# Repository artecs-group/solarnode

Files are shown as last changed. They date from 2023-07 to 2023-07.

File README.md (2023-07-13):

# Solar Node

This is a kikad project for a pcb of a IoT node that can meassure Solar Irradiation
and send it truogh a wifi conection to a cloud service.

The node ins based on an ESP32, which provides the microcontroller and the wifi
radio. The pcb adds a power supply system and a solar irradiance meassurement
circuit.

The power supply system is composed of a Lipo battery, a battery charger, a 6W
solar pannel and a set of regulators: one for the esp, and two for external
devices that can be swithced on or off from the ESP firmware.

The solar irradiance meassurement circuit is composed of a transimpedance
amplifier and a small mono-chrystalline fotovoltaic cell, that is kept in short
circuit by the transimpedance amplifier, which transforms the current generated
by the cell into a voltage that can be read using one of the ADC channels of the
ESP32. Bellow you can see an image of a complete node build from this pcb. 

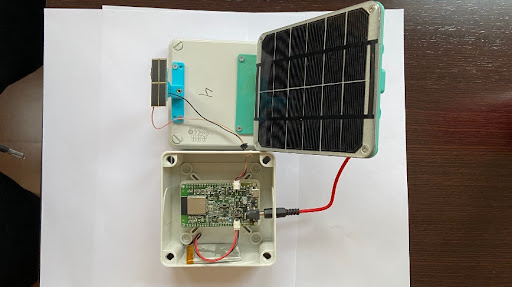
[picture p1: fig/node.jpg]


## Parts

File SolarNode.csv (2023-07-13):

Id | Designator | Package | Quantity | Designation | Supplier and ref
1 | SW5 | SW_SPST_B3U-1000P | 1 | IO0
2 | D9,D15,D4,D16 | D_SOD-323 | 4 | BAT48JFILM
3 | SW4 | SW_SPST_B3U-1000P | 1 | EN
4 | D3,D1 | D_SMA | 2 | MBRA340
5 | R20 | R_0603_1608Metric_0.65 | 1 | 453K
6 | H1,H3,H4,H2 | MountingHole_2.2mm_M2 | 4 | MountingHole
7 | R31,R30,R29 | R_0603_1608Metric_0.65 | 3 | 1M
8 | R8,R15,R28,R32,R7,R40,R25,R42,R33,R27,R9,R4,R6 | R_0603_1608Metric_0.65 | 13 | 10K
9 | U8 | MSOP-8_3x3mm_P0.65mm | 1 | OPA2356xxD
10 | C33,C45,C44,C32,C34,C23,C24,C19,C42,C30 | C_0603_1608Metric | 10 | 0.1u
11 | R12 | R_0603_1608Metric_0.65 | 1 | 5.90K
12 | R18 | R_0603_1608Metric_0.65 | 1 | 422K
13 | C1 | CP_Radial_D6.3mm_P2.50mm | 1 | 100u
14 | C3,C9,C20,C16,C27,C6,C5,C4,C22,C10,C36,C12,C8,C26,C2,C18,C11 | C_0603_1608Metric | 17 | 10u
15 | R5,R24,R11,R23,R22,R37 | R_0603_1608Metric_0.65 | 6 | 1K
16 | U3,U4 | SOT-23-5 | 2 | RT9080-33GJ5
17 | R10,R46,R45 | R_0603_1608Metric_0.65 | 3 | 0R
18 | R17 | R_0603_1608Metric_0.65 | 1 | 10M
19 | D7 | LED_0603_1608Metric | 1 | CHG
20 | Y1 | Crystal_SMD_3215-2Pin_3.2x1.5mm | 1 | 32.768KHz
21 | C40,C41 | C_0603_1608Metric | 2 | 12p
22 | FID3,FID1,FID4,FID2 | Fiducial_1mm_Mask3mm | 4 | Fiducial
23 | J2 | JST_PH_S2B-PH-SM4-TB_1x02-1MP_P2.00mm_Horizontal | 1 | TIA
24 | D11 | LED_0603_1608Metric | 1 | 3VA
25 | C14,C15 | C_0603_1608Metric | 2 | 1n
26 | R2,R3 | R_0603_1608Metric_0.65 | 2 | 5.1K
27 | U6 | QFN-24-1EP_4x4mm_P0.5mm_EP2.6x2.6mm | 1 | CP2104
28 | D6 | LED_0603_1608Metric | 1 | BATT!
29 | R26 | R_0603_1608Metric_0.65 | 1 | 30K
30 | U1 | VQFN-16-1EP_3x3mm_P0.5mm_EP1.6x1.6mm_ThermalVias | 1 | BQ24074RGT
31 | SW1 | SW_DPDT_CK_JS202011JCQN | 1 | BATT_SW
32 | R43 | R_0603_1608Metric_0.65 | 1 | 16.5R
33 | D14 | LED_0603_1608Metric | 1 | IO2
34 | C25 | C_0603_1608Metric | 1 | 1.8n
35 | R14 | R_0603_1608Metric_0.65 | 1 | 887R
36 | D8 | LED_0603_1608Metric | 1 | PG
37 | U7 | ESP32-WROOM-32 | 1 | ESP32-WROOM-32E
38 | J3 | GCT_USB4110-GF-A_REVB | 1 | USB_C_Receptacle_USB2.0
39 | L1 | L_Vishay_IFSC-1515AH_4x4x1.8mm | 1 | 8.2u
40 | SW3 | SW_SPST_B3U-1000P | 1 | LED
41 | U2 | SOT-23-6 | 1 | TPS3780A
42 | Q2 | SOT-363_SC-70-6 | 1 | MUN5214DW1
43 | J1 | BarrelJack_CLIFF_FC681465S_SMT_Horizontal | 1 | 10V_MAX
44 | R34,R35 | R_0603_1608Metric_0.65 | 2 | 2.2K
45 | R13 | R_0603_1608Metric_0.65 | 1 | 1.78K
46 | C38,C31 | C_0603_1608Metric | 2 | 1u
47 | U10 | SOT-363_SC-70-6 | 1 | NUP2202
48 | U9 | SOT-23-6 | 1 | MCP1501-10xCH
49 | D2 | LED_0603_1608Metric | 1 | DC!
50 | R16 | R_0603_1608Metric_0.65 | 1 | 750K
51 | J6 | JST_PH_S2B-PH-SM4-TB_1x02-1MP_P2.00mm_Horizontal | 1 | Li_3.7V
52 | R44 | R_0603_1608Metric_0.65 | 1 | 2R
53 | Q1 | SOT-23 | 1 | AO3400A
54 | R19 | R_0603_1608Metric_0.65 | 1 | 698K
55 | R41 | R_0603_1608Metric_0.65 | 1 | 7.5M
56 | SW2 | SW_DPDT_CK_JS202011JCQN | 1 | SYS_SW
57 | D13 | D_SOD-123F | 1 | MBR1020VL
58 | TH1 | C_Disc_D5.0mm_W2.5mm_P2.50mm | 1 | 103AT (NC)
59 | D10 | LED_0603_1608Metric | 1 | 3V
60 | U5 | SOT-23-5 | 1 | LM2735XMF
61 | R1 | R_0603_1608Metric_0.65 | 1 | 1K
62 | D12 | LED_0603_1608Metric | 1 | 5V
63 | R21 | R_0603_1608Metric_0.65 | 1 | 200K
64 | JP8 | SolderJumper-2_P1.3mm_Open_RoundedPad1.0x1.5mm | 1 | BOOST
65 | J5,J4 | PinHeader_1x18_P2.54mm_Vertical | 2 | Conn_01x18
66 | JP5 | SolderJumper-2_P1.3mm_Open_RoundedPad1.0x1.5mm | 1 | 0.50A
67 | JP7 | SolderJumper-2_P1.3mm_Open_RoundedPad1.0x1.5mm | 1 | SUP
68 | JP6 | SolderJumper-2_P1.3mm_Open_RoundedPad1.0x1.5mm | 1 | 1.00A
69 | JP3 | SolderJumper-2_P1.3mm_Open_RoundedPad1.0x1.5mm | 1 | TS
70 | JP4 | SolderJumper-2_P1.3mm_Open_RoundedPad1.0x1.5mm | 1 | 0.15A

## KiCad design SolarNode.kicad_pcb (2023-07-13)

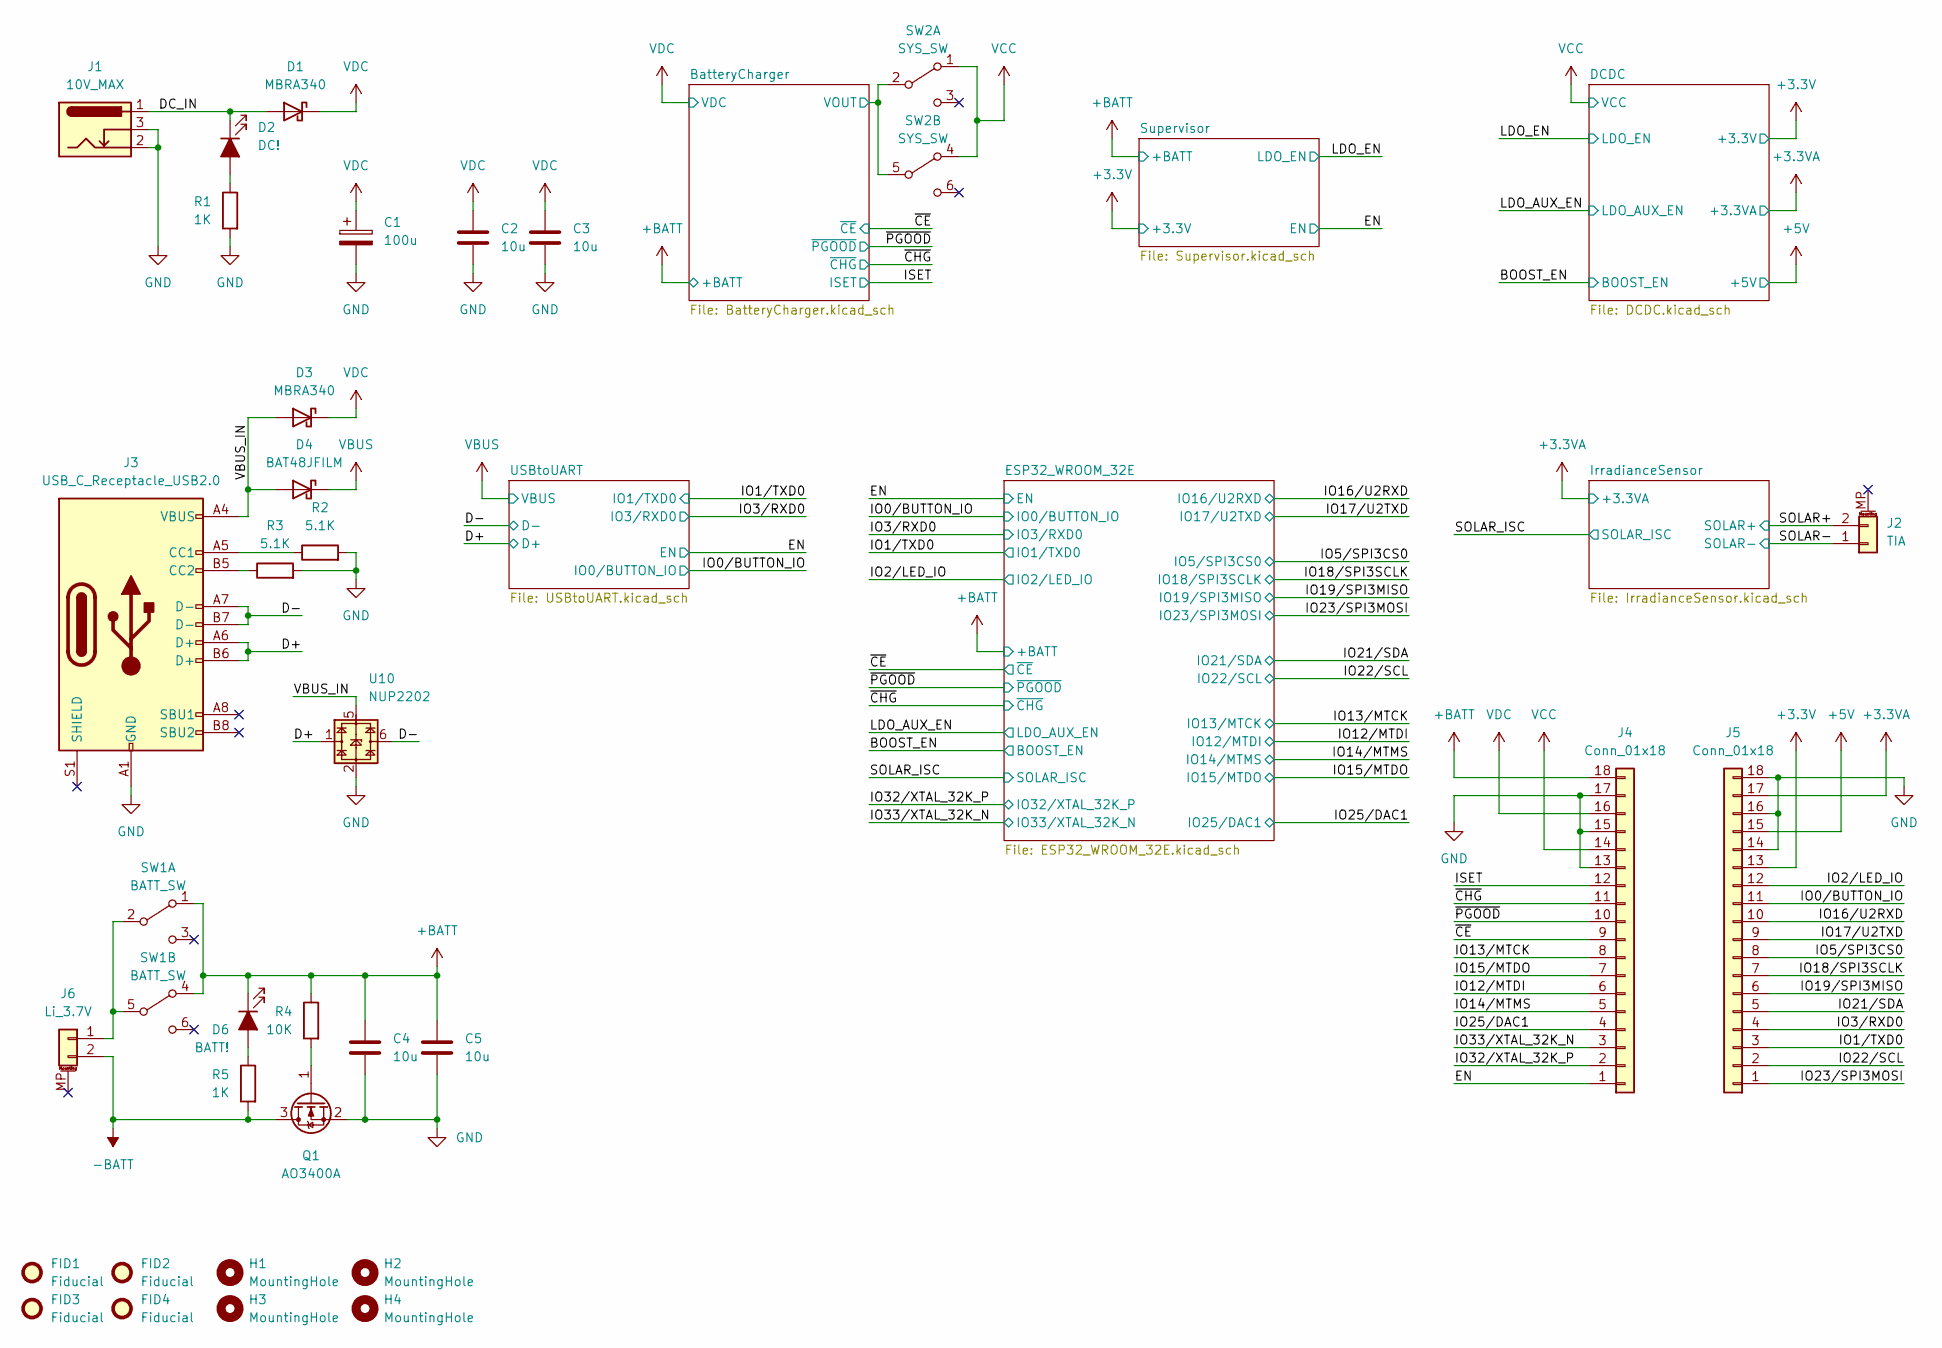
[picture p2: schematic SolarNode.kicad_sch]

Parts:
C1: 100u; CP_Radial_D6.3mm_P2.50mm; MPN 16YXF100MEFCT16.3X11
C2, C3, C4, C5: 10u; C_0603_1608Metric; MPN CC0603MRX5R7BB106
D1, D3: MBRA340; D_SMA; MPN MBRA340
D2: DC!; LED_0603_1608Metric; MPN 150060SS75000
D4: BAT48JFILM; D_SOD-323; MPN BAT48JFILM
D6: BATT!; LED_0603_1608Metric; MPN 150060SS75000
FID1, FID2, FID3, FID4: Fiducial; Fiducial_1mm_Mask3mm
H1, H2, H3, H4: MountingHole; MountingHole_2.2mm_M2
J1: 10V_MAX; BarrelJack_CLIFF_FC681465S_SMT_Horizontal; MPN FC681465S
J2: TIA; JST_PH_S2B-PH-SM4-TB_1x02-1MP_P2.00mm_Horizontal; MPN S2B-PH-SM4-TB(LF)(SN)
J3: USB_C_Receptacle_USB2.0; GCT_USB4110-GF-A_REVB; MPN USB4110-GF-A
J4, J5: Conn_01x18; PinHeader_1x18_P2.54mm_Vertical; MPN PH1-18-UA
J6: Li_3.7V; JST_PH_S2B-PH-SM4-TB_1x02-1MP_P2.00mm_Horizontal; MPN S2B-PH-SM4-TB(LF)(SN)
Q1: AO3400A; SOT-23; MPN AO3400A
R1, R5: 1K; R_0603_1608Metric_0.65; MPN RC0603FR-071KL
R2, R3: 5.1K; R_0603_1608Metric_0.65; MPN RC0603FR-075K1L
R4: 10K; R_0603_1608Metric_0.65; MPN RC0603FR-0710KL
SW1: BATT_SW; SW_DPDT_CK_JS202011JCQN; MPN JS202011JCQN
SW2: SYS_SW; SW_DPDT_CK_JS202011JCQN; MPN JS202011JCQN
U10: NUP2202; SOT-363_SC-70-6; MPN NUP2202W1T2G

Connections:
+3.3VA: J5.17; also elsewhere on the board
+3V3: J5.13; also elsewhere on the board
+5V: J5.15; also elsewhere on the board
+BATT: C4.1, C5.1, D6.1 (K), J4.18, R4.1, SW1.1 (A), SW1.4 (A); also elsewhere on the board
-BATT: J6.2, Q1.3 (D), R5.2
/BatteryCharger/VOUT: SW2.2 (B), SW2.5 (B); also elsewhere on the board
/D+: J3.A6 (D+), J3.B6 (D+), U10.1; also elsewhere on the board
/D-: J3.A7 (D-), J3.B7 (D-), U10.6; also elsewhere on the board
/DC_IN: D1.2 (A), D2.1 (K), J1.1
/EN: J4.1; also elsewhere on the board
/IO0/BUTTON_IO: J5.11; also elsewhere on the board
/IO1/TXD0: J5.3; also elsewhere on the board
/IO2/LED_IO: J5.12; also elsewhere on the board
/IO3/RXD0: J5.4; also elsewhere on the board
/IO5/SPI3CS0: J5.8; also elsewhere on the board
/IO12/MTDI: J4.6; also elsewhere on the board
/IO13/MTCK: J4.8; also elsewhere on the board
/IO14/MTMS: J4.5; also elsewhere on the board
/IO15/MTDO: J4.7; also elsewhere on the board
/IO16/U2RXD: J5.10; also elsewhere on the board
/IO17/U2TXD: J5.9; also elsewhere on the board
/IO18/SPI3SCLK: J5.7; also elsewhere on the board
/IO19/SPI3MISO: J5.6; also elsewhere on the board
/IO21/SDA: J5.5; also elsewhere on the board
/IO22/SCL: J5.2; also elsewhere on the board
/IO23/SPI3MOSI: J5.1; also elsewhere on the board
/IO25/DAC1: J4.4; also elsewhere on the board
/IO32/XTAL_32K_P: J4.2; also elsewhere on the board
/IO33/XTAL_32K_N: J4.3; also elsewhere on the board
/ISET: J4.12; also elsewhere on the board
/SOLAR+: J2.2; also elsewhere on the board
/SOLAR-: J2.1; also elsewhere on the board
/VBUS_IN: D3.2 (A), D4.2 (A), J3.A4 (VBUS), J3.A9 (VBUS), J3.B4 (VBUS), J3.B9 (VBUS), U10.5
/~CE: J4.9; also elsewhere on the board
/~CHG: J4.11; also elsewhere on the board
/~PGOOD: J4.10; also elsewhere on the board
GND: C1.2, C2.2, C3.2, C4.2, C5.2, J1.2, J1.3, J3.A1 (GND), J3.A12 (GND), J3.B1 (GND), J3.B12 (GND), J4.13, J4.15, J4.17, J5.14, J5.16, J5.18, Q1.2 (S), R1.2, R2.2, R3.2, U10.2; also elsewhere on the board
unnamed: D2.2 (A), R1.1
unnamed: D6.2 (A), R5.1
unnamed: J3.A5 (CC1), R2.1
unnamed: J3.B5 (CC2), R3.1
unnamed: J6.1, SW1.2 (B), SW1.5 (B)
unnamed: Q1.1 (G), R4.2
VBUS: D4.1 (K); also elsewhere on the board
VCC: J4.14, SW2.1 (A), SW2.4 (A); also elsewhere on the board
VDC: C1.1, C2.1, C3.1, D1.1 (K), D3.1 (K), J4.16; also elsewhere on the board

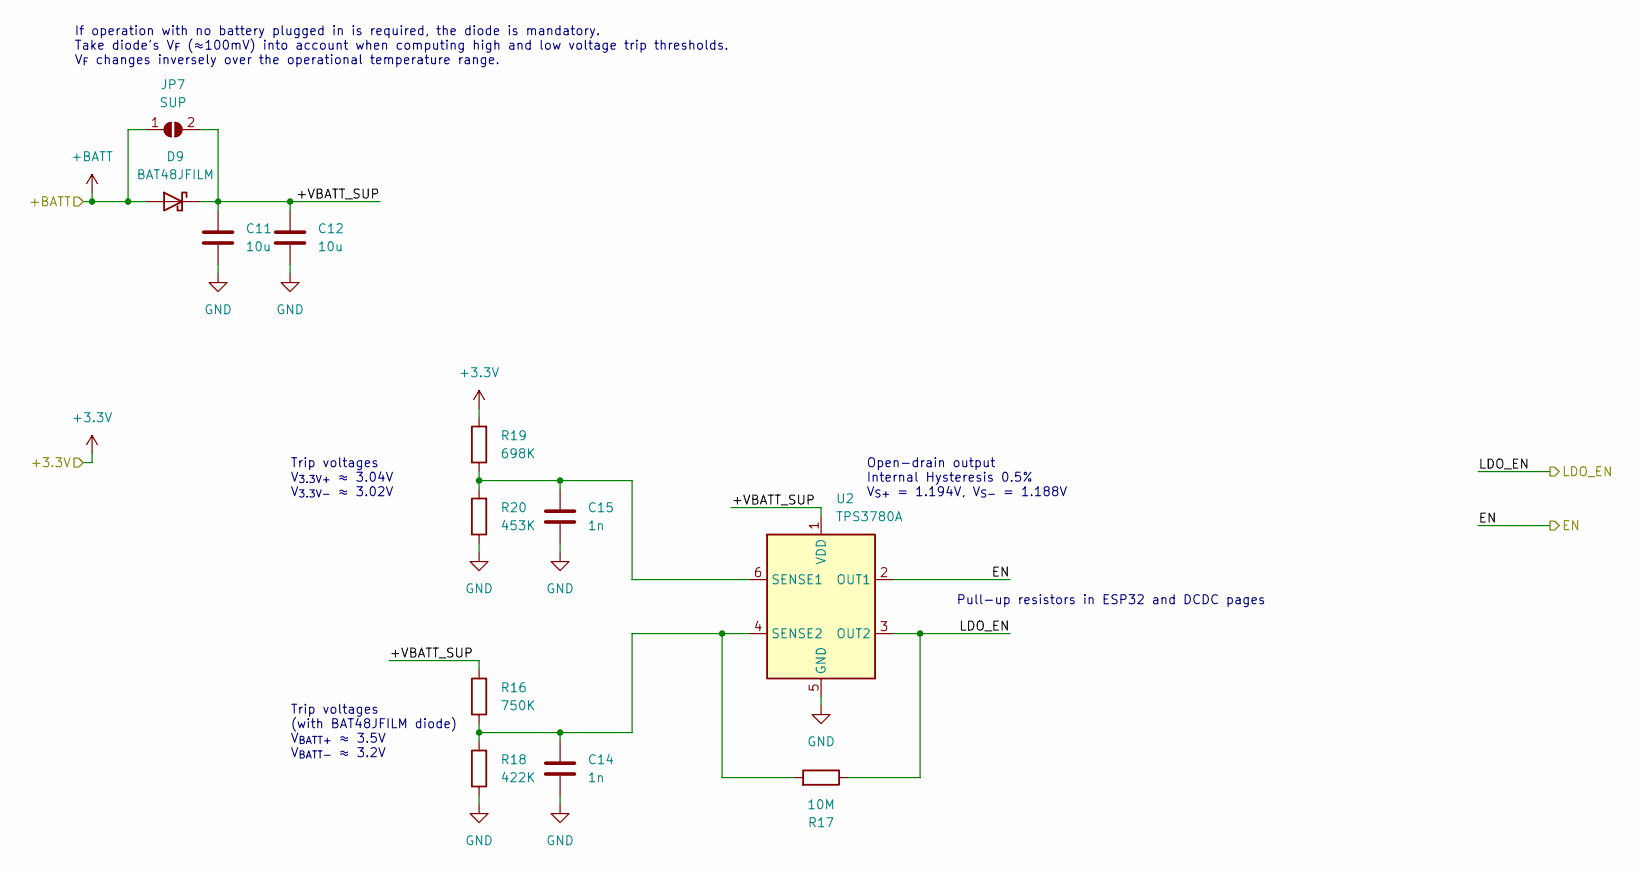
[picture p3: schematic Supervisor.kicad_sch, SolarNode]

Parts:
C11, C12: 10u; C_0603_1608Metric; MPN CC0603MRX5R7BB106
C14, C15: 1n; C_0603_1608Metric; MPN CC0603KRX7R9BB102
D9: BAT48JFILM; D_SOD-323; MPN BAT48JFILM
JP7: SUP; SolderJumper-2_P1.3mm_Open_RoundedPad1.0x1.5mm
R16: 750K; R_0603_1608Metric_0.65; MPN RC0603FR-07750KL
R17: 10M; R_0603_1608Metric_0.65; MPN RC0603FR-0710ML
R18: 422K; R_0603_1608Metric_0.65; MPN RC0603FR-07422KL
R19: 698K; R_0603_1608Metric_0.65; MPN RC0603FR-07698KL
R20: 453K; R_0603_1608Metric_0.65; MPN RC0603FR-07453KL
U2: TPS3780A; SOT-23-6; MPN TPS3780ADBVT

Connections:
+3V3: R19.2; also elsewhere on the board
+BATT: D9.2 (A), JP7.1 (A); also elsewhere on the board
/EN: U2.2 (OUT1); also elsewhere on the board
/LDO_EN: R17.1, U2.3 (OUT2); also elsewhere on the board
/Supervisor/+VBATT_SUP: C11.1, C12.1, D9.1 (K), JP7.2 (B), R16.2, U2.1 (VDD)
GND: C11.2, C12.2, C14.2, C15.2, R18.1, R20.1, U2.5 (GND); also elsewhere on the board
unnamed: C14.1, R16.1, R17.2, R18.2, U2.4 (SENSE2)
unnamed: C15.1, R19.1, R20.2, U2.6 (SENSE1)

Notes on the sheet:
Trip voltages V_{3.3V+} ≈ 3.04V V_{3.3V-} ≈ 3.02V
Pull-up resistors in ESP32 and DCDC pages
Trip voltages (with BAT48JFILM diode) V_{BATT+} ≈ 3.5V V_{BATT-} ≈ 3.2V
If operation with no battery plugged in is required, the diode is mandatory. Take diode's V_{F} (≈100mV) into account when computing high and low voltage trip thresholds. V_{F} changes inversely over the operational temperature range.
Open-drain output Internal Hysteresis 0.5% V_{S+} = 1.194V, V_{S-} = 1.188V

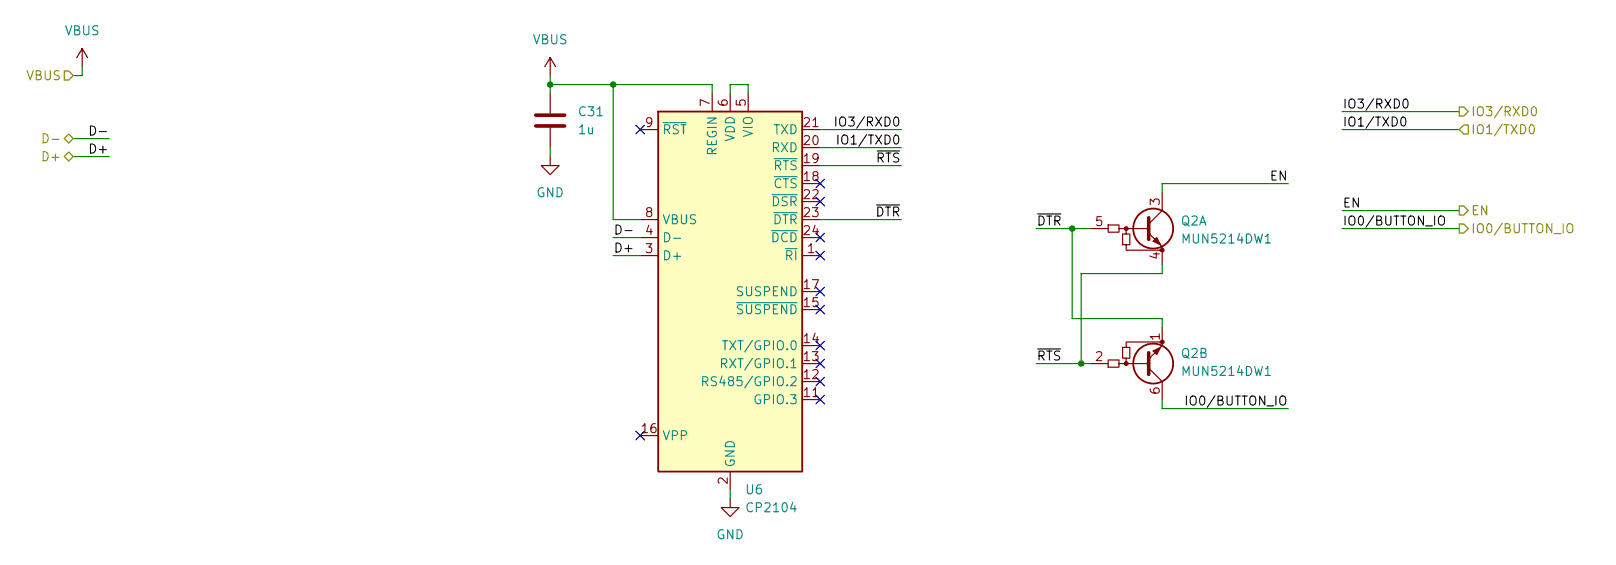
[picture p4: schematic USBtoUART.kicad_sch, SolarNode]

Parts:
C31: 1u; C_0603_1608Metric; MPN CC0603KRX7R8BB105
Q2: MUN5214DW1; SOT-363_SC-70-6; MPN MUN5214DW1T1G
U6: CP2104; QFN-24-1EP_4x4mm_P0.5mm_EP2.6x2.6mm; MPN CP2104-F03-GM

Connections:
/D+: U6.3 (D+); also elsewhere on the board
/D-: U6.4 (D-); also elsewhere on the board
/EN: Q2.3 (C1); also elsewhere on the board
/IO0/BUTTON_IO: Q2.6 (C2); also elsewhere on the board
/IO1/TXD0: U6.20 (RXD); also elsewhere on the board
/IO3/RXD0: U6.21 (TXD); also elsewhere on the board
/USBtoUART/~DTR: Q2.1 (E2), Q2.5 (B1), U6.23 (~DTR)
/USBtoUART/~RTS: Q2.2 (B2), Q2.4 (E1), U6.19 (~RTS)
GND: C31.2, U6.2 (GND), U6.25 (GND); also elsewhere on the board
unnamed: U6.5 (VIO), U6.6 (VDD)
VBUS: C31.1, U6.7 (REGIN), U6.8 (VBUS); also elsewhere on the board

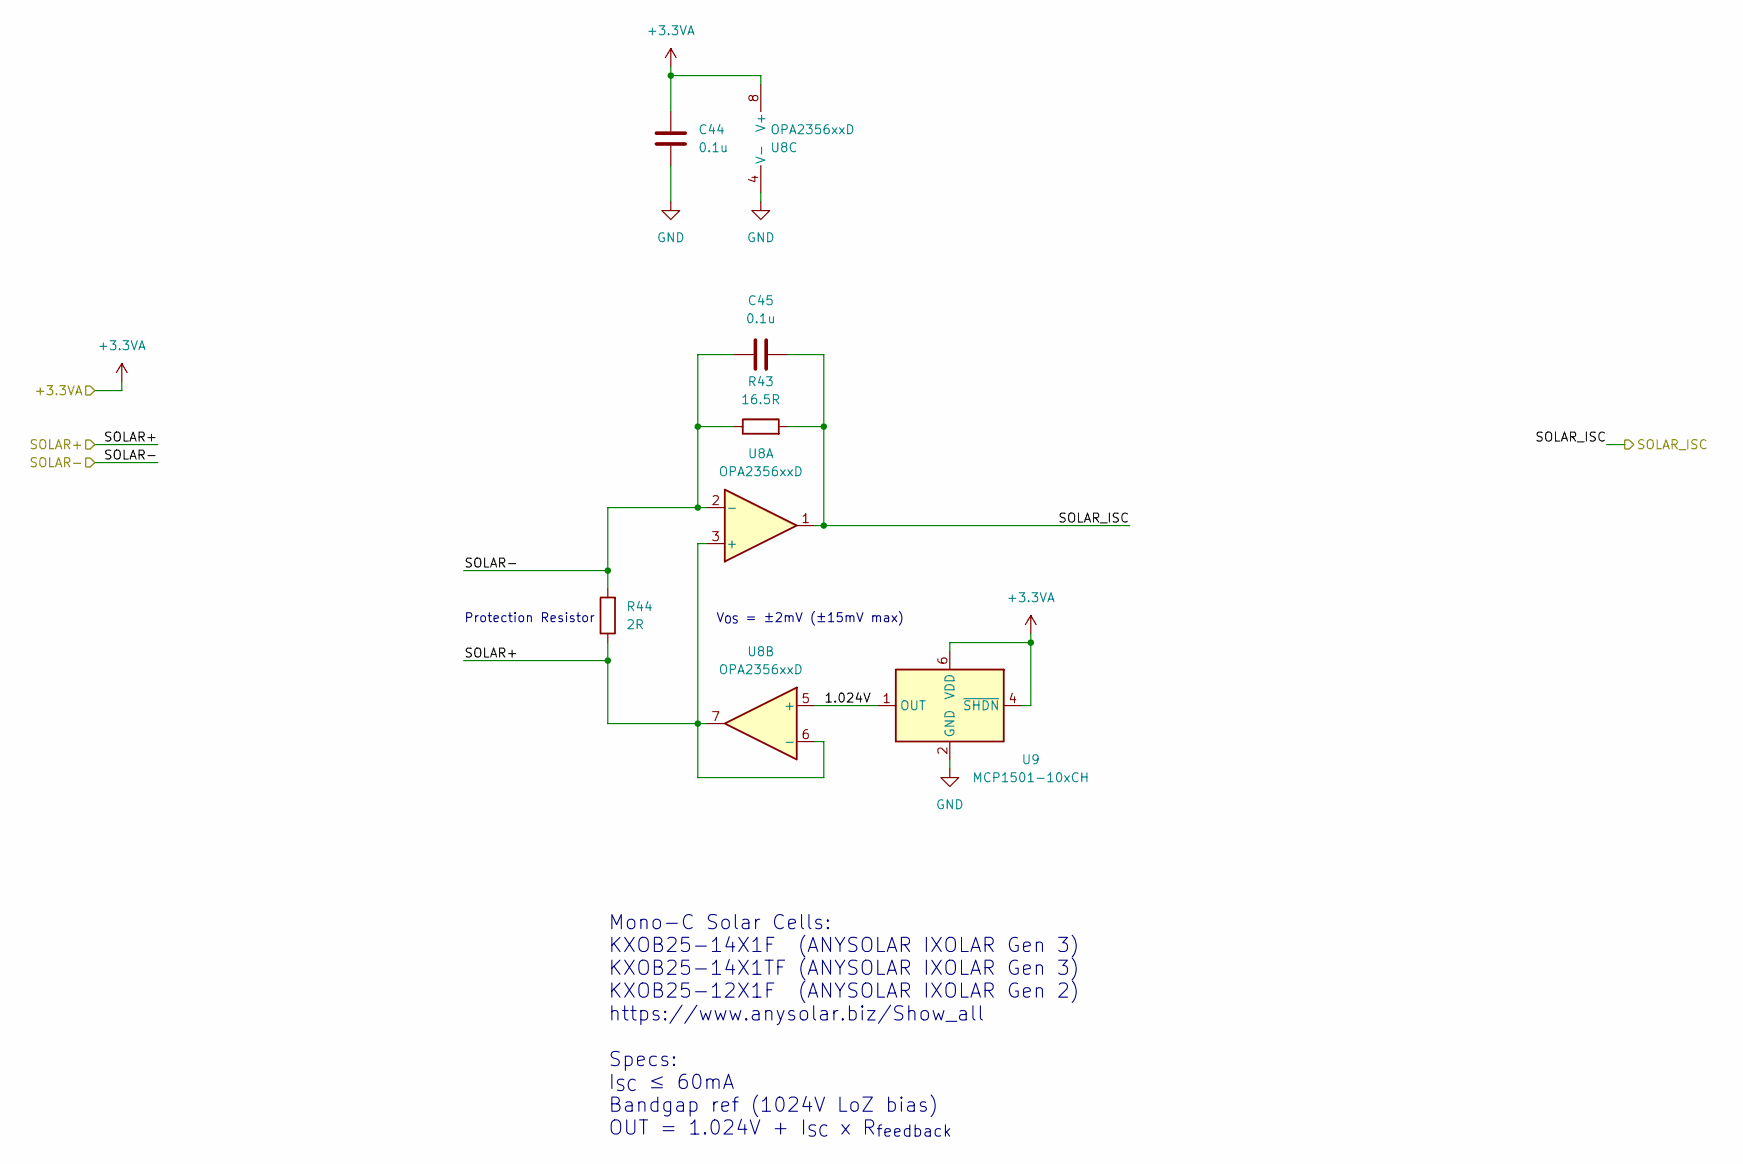
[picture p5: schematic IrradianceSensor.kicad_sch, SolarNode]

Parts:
C44, C45: 0.1u; C_0603_1608Metric; MPN CC0603KRX7R9BB104
R43: 16.5R; R_0603_1608Metric_0.65; MPN RC0603FR-0716R5L
R44: 2R; R_0603_1608Metric_0.65; MPN RC0603FR-072RL
U8: OPA2356xxD; MSOP-8_3x3mm_P0.65mm; MPN OPA2356AIDGKR
U9: MCP1501-10xCH; SOT-23-6; MPN MCP1501T-10E/CHY

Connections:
+3.3VA: C44.1, U8.8 (V+), U9.4 (~SHDN), U9.6 (VDD); also elsewhere on the board
/IrradianceSensor/1.024V: U8.5 (+), U9.1 (OUT)
/SOLAR+: R44.1, U8.3 (+), U8.6 (-), U8.7; also elsewhere on the board
/SOLAR-: C45.1, R43.1, R44.2, U8.2 (-); also elsewhere on the board
/SOLAR_ISC: C45.2, R43.2, U8.1; also elsewhere on the board
GND: C44.2, U8.4 (V-), U9.2 (GND), U9.3 (GND), U9.5 (GND); also elsewhere on the board

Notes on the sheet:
Mono-C Solar Cells: KXOB25-14X1F (ANYSOLAR IXOLAR Gen 3) KXOB25-14X1TF (ANYSOLAR IXOLAR Gen 3) KXOB25-12X1F (ANYSOLAR IXOLAR Gen 2) https://www.anysolar.biz/Show_all Specs: I_{SC} ≤ 60mA Bandgap ref (1024V LoZ bias) OUT = 1.024V + I_{SC} x R_{feedback}
V_{OS} = ±2mV (±15mV max)
Protection Resistor

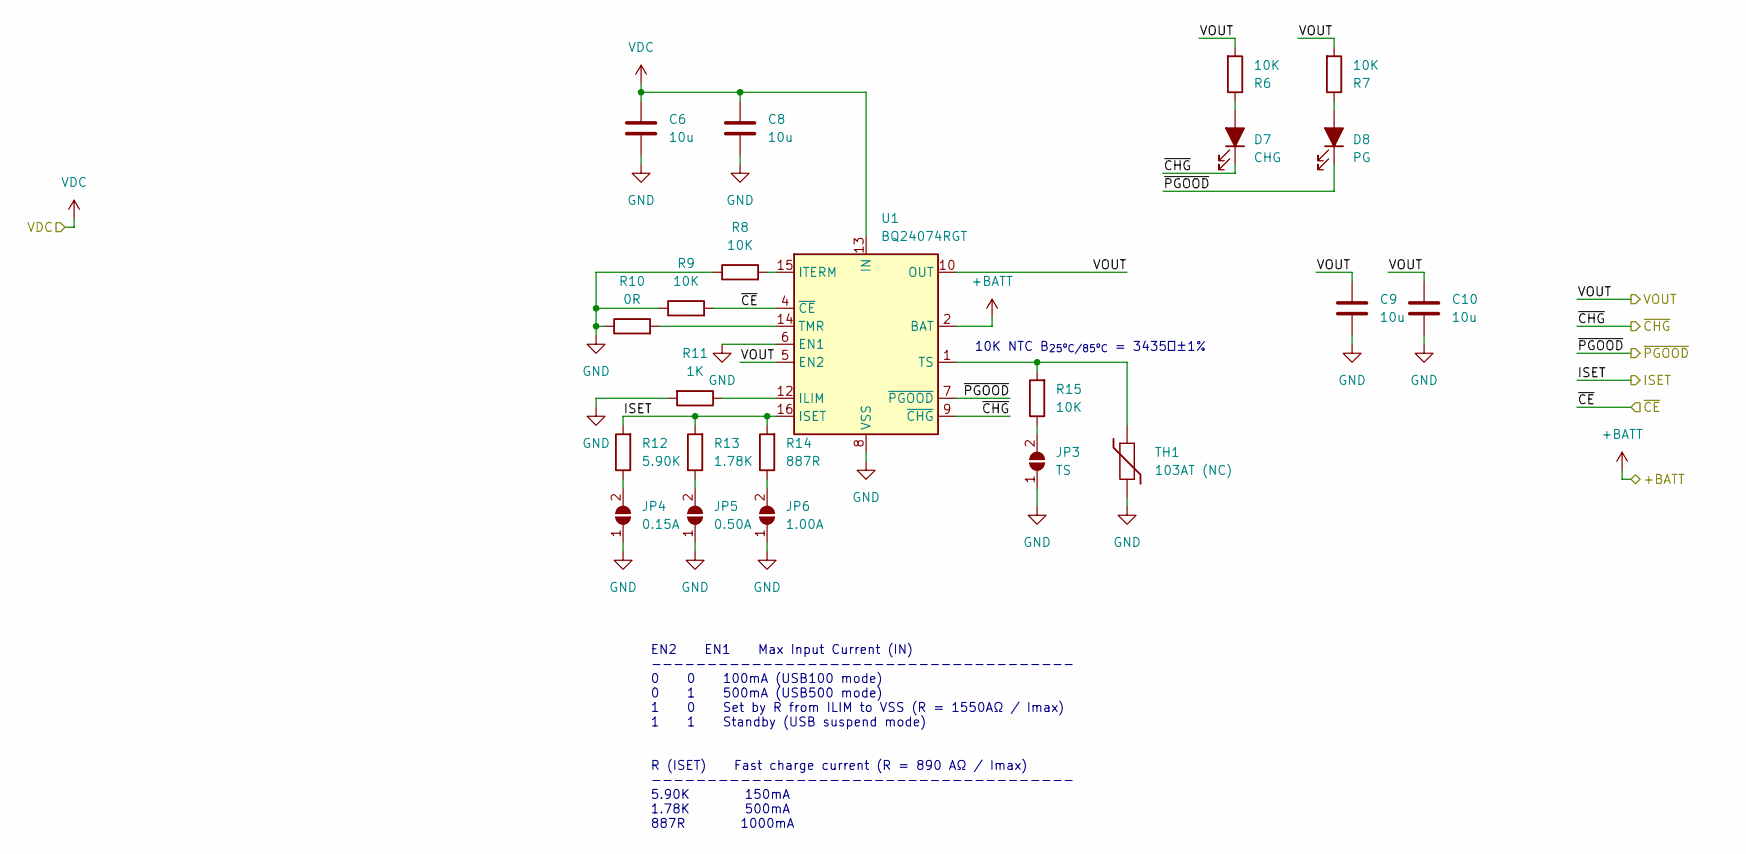
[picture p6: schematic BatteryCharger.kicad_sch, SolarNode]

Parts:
C6, C8, C9, C10: 10u; C_0603_1608Metric; MPN CC0603MRX5R7BB106
D7: CHG; LED_0603_1608Metric; MPN 150060SS75000
D8: PG; LED_0603_1608Metric; MPN 150060VS75000
JP3: TS; SolderJumper-2_P1.3mm_Open_RoundedPad1.0x1.5mm
JP4: 0.15A; SolderJumper-2_P1.3mm_Open_RoundedPad1.0x1.5mm
JP5: 0.50A; SolderJumper-2_P1.3mm_Open_RoundedPad1.0x1.5mm
JP6: 1.00A; SolderJumper-2_P1.3mm_Open_RoundedPad1.0x1.5mm
R6, R7, R8, R9, R15: 10K; R_0603_1608Metric_0.65; MPN RC0603FR-0710KL
R10: 0R; R_0603_1608Metric_0.65; MPN RC0603FR-070RL
R11: 1K; R_0603_1608Metric_0.65; MPN RC0603FR-071KL
R12: 5.90K; R_0603_1608Metric_0.65; MPN RC0603FR-075K9L
R13: 1.78K; R_0603_1608Metric_0.65; MPN RC0603FR-071K78L
R14: 887R; R_0603_1608Metric_0.65; MPN RC0603FR-07887RL
TH1: 103AT (NC); C_Disc_D5.0mm_W2.5mm_P2.50mm; MPN 103AT-2
U1: BQ24074RGT; VQFN-16-1EP_3x3mm_P0.5mm_EP1.6x1.6mm_ThermalVias; MPN BQ24074RGT

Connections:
+BATT: U1.2 (BAT), U1.3 (BAT); also elsewhere on the board
/BatteryCharger/VOUT: C9.1, C10.1, R6.2, R7.2, U1.5 (EN2), U1.10 (OUT), U1.11 (OUT); also elsewhere on the board
/ISET: R12.2, R13.2, R14.2, U1.16 (ISET); also elsewhere on the board
/~CE: R9.2, U1.4 (~CE); also elsewhere on the board
/~CHG: D7.1 (K), U1.9 (~CHG); also elsewhere on the board
/~PGOOD: D8.1 (K), U1.7 (~PGOOD); also elsewhere on the board
GND: C6.2, C8.2, C9.2, C10.2, JP3.1 (A), JP4.1 (A), JP5.1 (A), JP6.1 (A), R8.1, R9.1, R10.1, R11.2, TH1.2, U1.6 (EN1), U1.8 (VSS), U1.17 (VSS); also elsewhere on the board
unnamed: D7.2 (A), R6.1
unnamed: D8.2 (A), R7.1
unnamed: JP3.2 (B), R15.1
unnamed: JP4.2 (B), R12.1
unnamed: JP5.2 (B), R13.1
unnamed: JP6.2 (B), R14.1
unnamed: R8.2, U1.15 (ITERM)
unnamed: R10.2, U1.14 (TMR)
unnamed: R11.1, U1.12 (ILIM)
unnamed: R15.2, TH1.1, U1.1 (TS)
VDC: C6.1, C8.1, U1.13 (IN); also elsewhere on the board

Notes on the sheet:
EN2 EN1 Max Input Current (IN) -------------------------------------- 0 0 100mA (USB100 mode) 0 1 500mA (USB500 mode) 1 0 Set by R from ILIM to VSS (R = 1550AΩ / Imax) 1 1 Standby (USB suspend mode) R (ISET) Fast charge current (R = 890 AΩ / Imax) -------------------------------------- 5.90K 150mA 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
10K NTC B_{25ºC/85ºC} = 3435Ｋ±1%

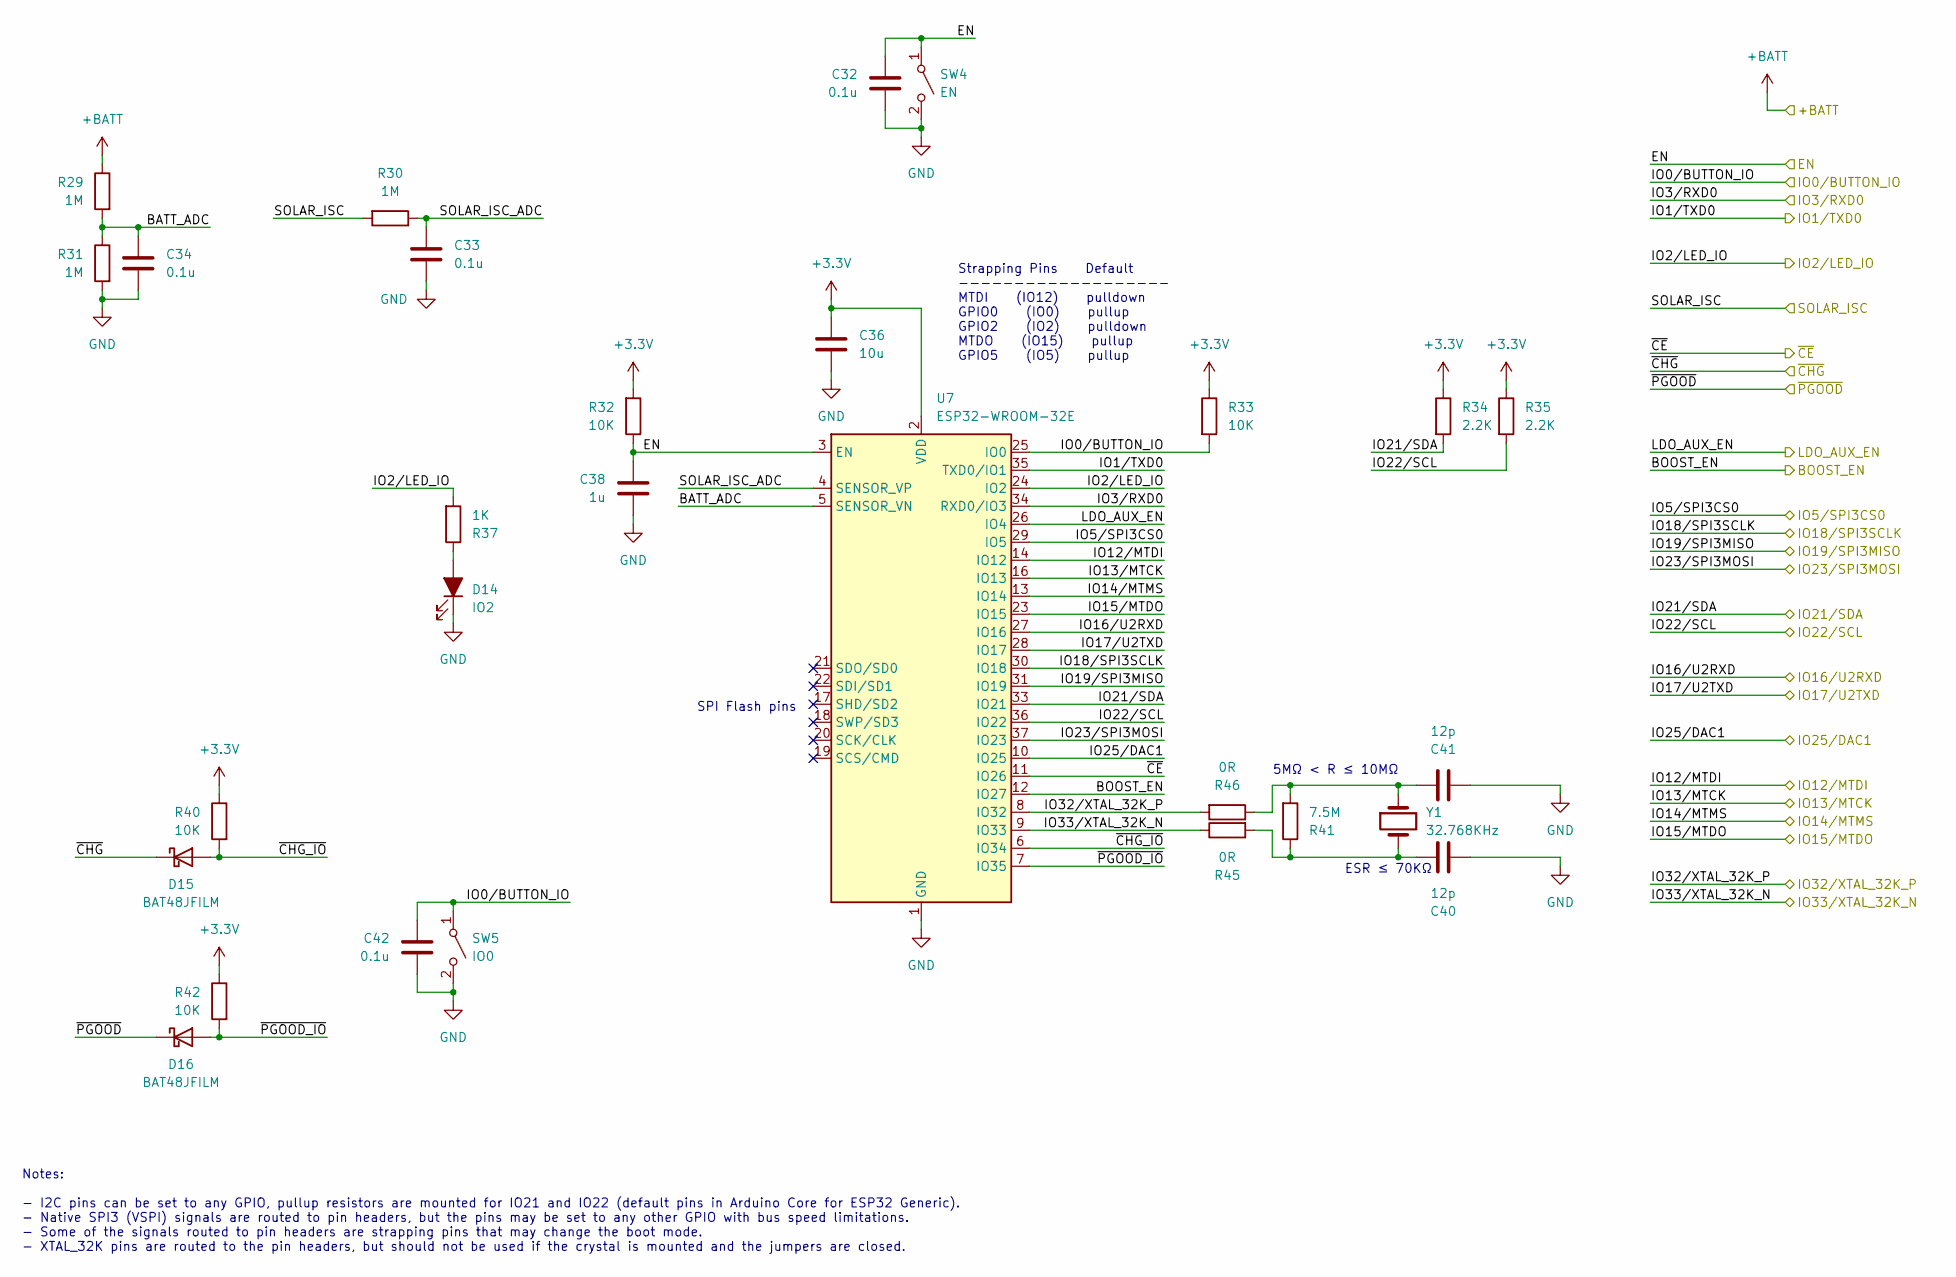
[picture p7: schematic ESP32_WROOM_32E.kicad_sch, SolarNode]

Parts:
C32, C33, C34, C42: 0.1u; C_0603_1608Metric; MPN CC0603KRX7R9BB104
C36: 10u; C_0603_1608Metric; MPN CC0603MRX5R7BB106
C38: 1u; C_0603_1608Metric; MPN CC0603KRX7R8BB105
C40, C41: 12p; C_0603_1608Metric; MPN CC0603KRNPO9BN120
D14: IO2; LED_0603_1608Metric; MPN 150060VS75000
D15, D16: BAT48JFILM; D_SOD-323; MPN BAT48JFILM
R29, R30, R31: 1M; R_0603_1608Metric_0.65; MPN RC0603FR-071ML
R32, R33, R40, R42: 10K; R_0603_1608Metric_0.65; MPN RC0603FR-0710KL
R34, R35: 2.2K; R_0603_1608Metric_0.65; MPN RC0603FR-072K2L
R37: 1K; R_0603_1608Metric_0.65; MPN RC0603FR-071KL
R41: 7.5M; R_0603_1608Metric_0.65; MPN RC0603FR-077M5L
R45, R46: 0R; R_0603_1608Metric_0.65; MPN RC0603FR-070RL
SW4: EN; SW_SPST_B3U-1000P; MPN B3U-1000P
SW5: IO0; SW_SPST_B3U-1000P; MPN B3U-1000P
U7: ESP32-WROOM-32E; ESP32-WROOM-32; MPN ESP32-WROOM-32E (4MB)
Y1: 32.768KHz; Crystal_SMD_3215-2Pin_3.2x1.5mm; MPN FC-135 32.7680KA-K0

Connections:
+3V3: C36.1, R32.2, R33.1, R34.1, R35.1, R40.1, R42.1, U7.2 (VDD); also elsewhere on the board
+BATT: R29.1; also elsewhere on the board
/BOOST_EN: U7.12 (IO27); also elsewhere on the board
/EN: C32.1, C38.2, R32.1, SW4.1 (A), U7.3 (EN); also elsewhere on the board
/ESP32_WROOM_32E/BATT_ADC: C34.1, R29.2, R31.1, U7.5 (SENSOR_VN)
/ESP32_WROOM_32E/SOLAR_ISC_ADC: C33.1, R30.1, U7.4 (SENSOR_VP)
/ESP32_WROOM_32E/~CHG_IO: D15.2 (A), R40.2, U7.6 (IO34)
/ESP32_WROOM_32E/~PGOOD_IO: D16.2 (A), R42.2, U7.7 (IO35)
/IO0/BUTTON_IO: C42.1, R33.2, SW5.1 (A), U7.25 (IO0); also elsewhere on the board
/IO1/TXD0: U7.35 (TXD0/IO1); also elsewhere on the board
/IO2/LED_IO: R37.2, U7.24 (IO2); also elsewhere on the board
/IO3/RXD0: U7.34 (RXD0/IO3); also elsewhere on the board
/IO5/SPI3CS0: U7.29 (IO5); also elsewhere on the board
/IO12/MTDI: U7.14 (IO12); also elsewhere on the board
/IO13/MTCK: U7.16 (IO13); also elsewhere on the board
/IO14/MTMS: U7.13 (IO14); also elsewhere on the board
/IO15/MTDO: U7.23 (IO15); also elsewhere on the board
/IO16/U2RXD: U7.27 (IO16); also elsewhere on the board
/IO17/U2TXD: U7.28 (IO17); also elsewhere on the board
/IO18/SPI3SCLK: U7.30 (IO18); also elsewhere on the board
/IO19/SPI3MISO: U7.31 (IO19); also elsewhere on the board
/IO21/SDA: R34.2, U7.33 (IO21); also elsewhere on the board
/IO22/SCL: R35.2, U7.36 (IO22); also elsewhere on the board
/IO23/SPI3MOSI: U7.37 (IO23); also elsewhere on the board
/IO25/DAC1: U7.10 (IO25); also elsewhere on the board
/IO32/XTAL_32K_P: R46.2, U7.8 (IO32); also elsewhere on the board
/IO33/XTAL_32K_N: R45.1, U7.9 (IO33); also elsewhere on the board
/LDO_AUX_EN: U7.26 (IO4); also elsewhere on the board
/SOLAR_ISC: R30.2; also elsewhere on the board
/~CE: U7.11 (IO26); also elsewhere on the board
/~CHG: D15.1 (K); also elsewhere on the board
/~PGOOD: D16.1 (K); also elsewhere on the board
GND: C32.2, C33.2, C34.2, C36.2, C38.1, C40.2, C41.2, C42.2, D14.1 (K), R31.2, SW4.2 (B), SW5.2 (B), U7.1 (GND), U7.15 (GND), U7.38 (GND), U7.39 (GND); also elsewhere on the board
unnamed: C40.1, R41.1, R45.2, Y1.2
unnamed: C41.1, R41.2, R46.1, Y1.1
unnamed: D14.2 (A), R37.1

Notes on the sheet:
Strapping Pins Default ------------------- MTDI (IO12) pulldown GPIO0 (IO0) pullup GPIO2 (IO2) pulldown MTDO (IO15) pullup GPIO5 (IO5) pullup
SPI Flash pins
Notes: - I2C pins can be set to any GPIO, pullup resistors are mounted for IO21 and IO22 (default pins in Arduino Core for ESP32 Generic). - Native SPI3 (VSPI) signals are routed to pin headers, but the pins may be set to any other GPIO with bus speed limitations. - Some of the signals routed to pi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
5MΩ < R ≤ 10MΩ
ESR ≤ 70KΩ

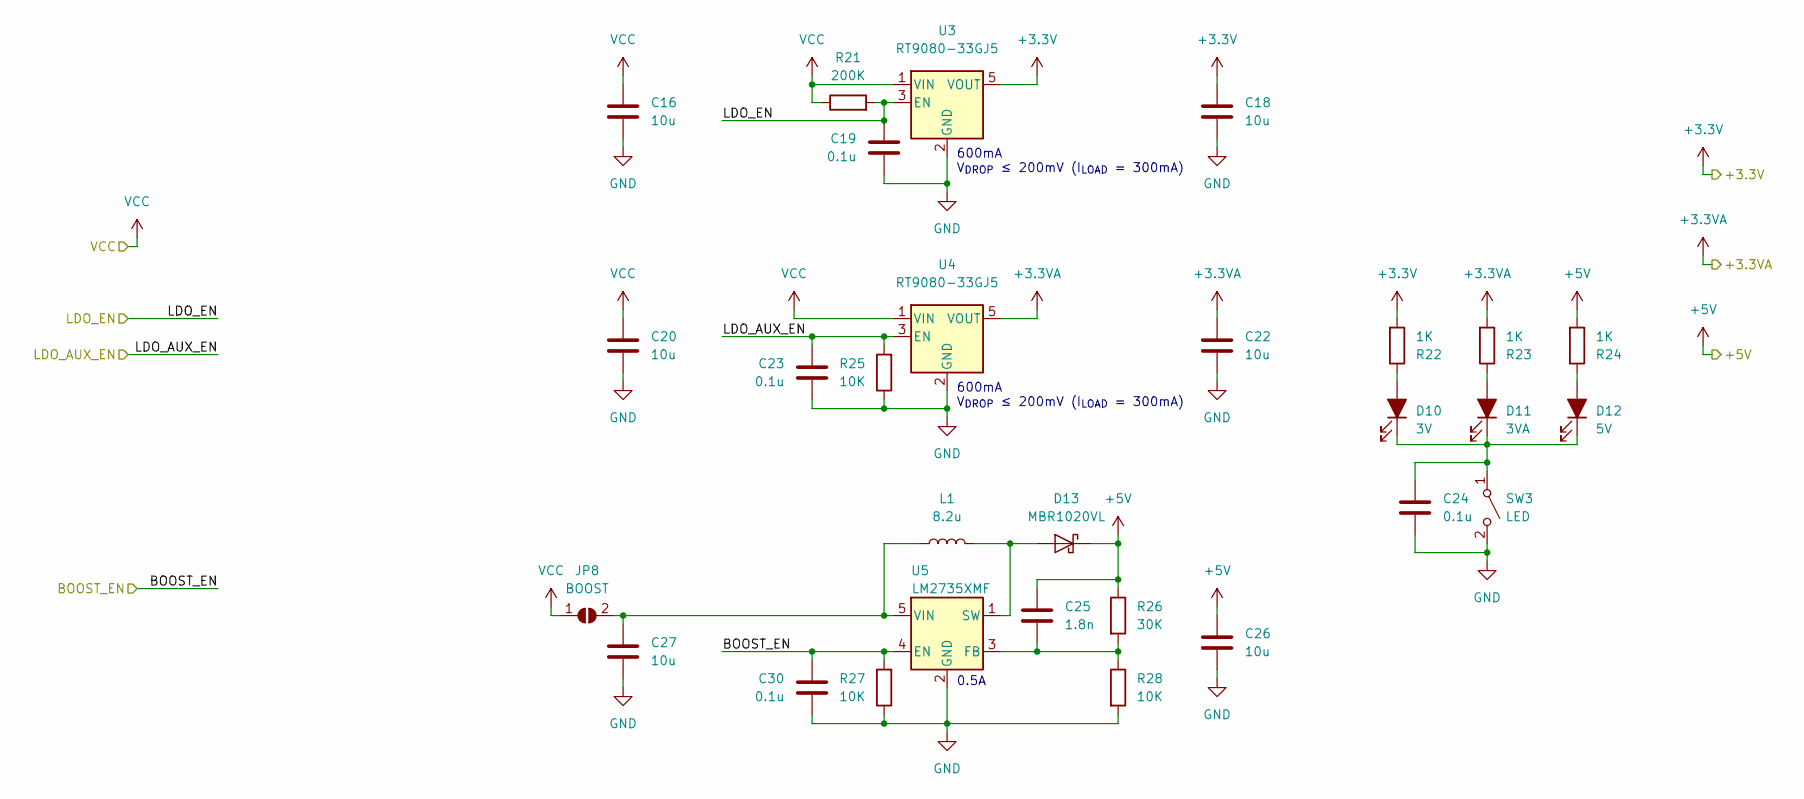
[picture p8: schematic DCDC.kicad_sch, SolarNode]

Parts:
C16, C18, C20, C22, C26, C27: 10u; C_0603_1608Metric; MPN CC0603MRX5R7BB106
C19, C23, C24, C30: 0.1u; C_0603_1608Metric; MPN CC0603KRX7R9BB104
C25: 1.8n; C_0603_1608Metric; MPN CC0603KRX7R9BB182
D10: 3V; LED_0603_1608Metric; MPN 150060VS75000
D11: 3VA; LED_0603_1608Metric; MPN 150060VS75000
D12: 5V; LED_0603_1608Metric; MPN 150060VS75000
D13: MBR1020VL; D_SOD-123F; MPN MBR1020VL
JP8: BOOST; SolderJumper-2_P1.3mm_Open_RoundedPad1.0x1.5mm
L1: 8.2u; L_Vishay_IFSC-1515AH_4x4x1.8mm; MPN IFSC1515AHER8R2M01
R21: 200K; R_0603_1608Metric_0.65; MPN RC0603FR-07200KL
R22, R23, R24: 1K; R_0603_1608Metric_0.65; MPN RC0603FR-071KL
R25, R27, R28: 10K; R_0603_1608Metric_0.65; MPN RC0603FR-0710KL
R26: 30K; R_0603_1608Metric_0.65; MPN RC0603FR-0730KL
SW3: LED; SW_SPST_B3U-1000P; MPN B3U-1000P
U3, U4: RT9080-33GJ5; SOT-23-5; MPN RT9080-33GJ5
U5: LM2735XMF; SOT-23-5; MPN LM2735XMF/NOPB

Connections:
+3.3VA: C22.1, R23.2, U4.5 (VOUT); also elsewhere on the board
+3V3: C18.1, R22.2, U3.5 (VOUT); also elsewhere on the board
+5V: C25.1, C26.1, D13.1 (K), R24.2, R26.1; also elsewhere on the board
/BOOST_EN: C30.1, R27.2, U5.4 (EN); also elsewhere on the board
/LDO_AUX_EN: C23.1, R25.2, U4.3 (EN); also elsewhere on the board
/LDO_EN: C19.1, R21.2, U3.3 (EN); also elsewhere on the board
GND: C16.2, C18.2, C19.2, C20.2, C22.2, C23.2, C24.2, C26.2, C27.2, C30.2, R25.1, R27.1, R28.2, SW3.2 (B), U3.2 (GND), U4.2 (GND), U5.2 (GND); also elsewhere on the board
unnamed: C24.1, D10.1 (K), D11.1 (K), D12.1 (K), SW3.1 (A)
unnamed: C25.2, R26.2, R28.1, U5.3 (FB)
unnamed: C27.1, JP8.2 (B), L1.1, U5.5 (VIN)
unnamed: D10.2 (A), R22.1
unnamed: D11.2 (A), R23.1
unnamed: D12.2 (A), R24.1
unnamed: D13.2 (A), L1.2, U5.1 (SW)
VCC: C16.1, C20.1, JP8.1 (A), R21.1, U3.1 (VIN), U4.1 (VIN); also elsewhere on the board

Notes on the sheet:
0.5A
600mA V_{DROP} ≤ 200mV (I_{LOAD} = 300mA)

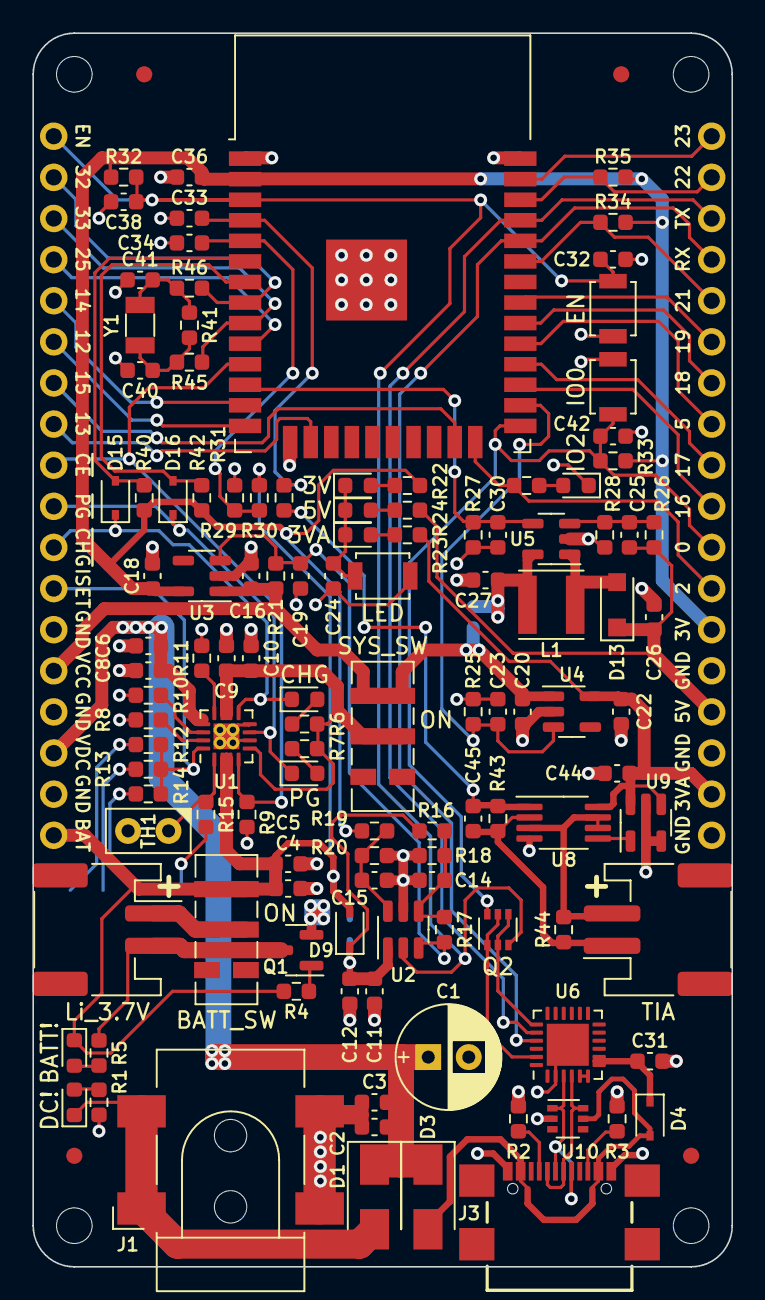
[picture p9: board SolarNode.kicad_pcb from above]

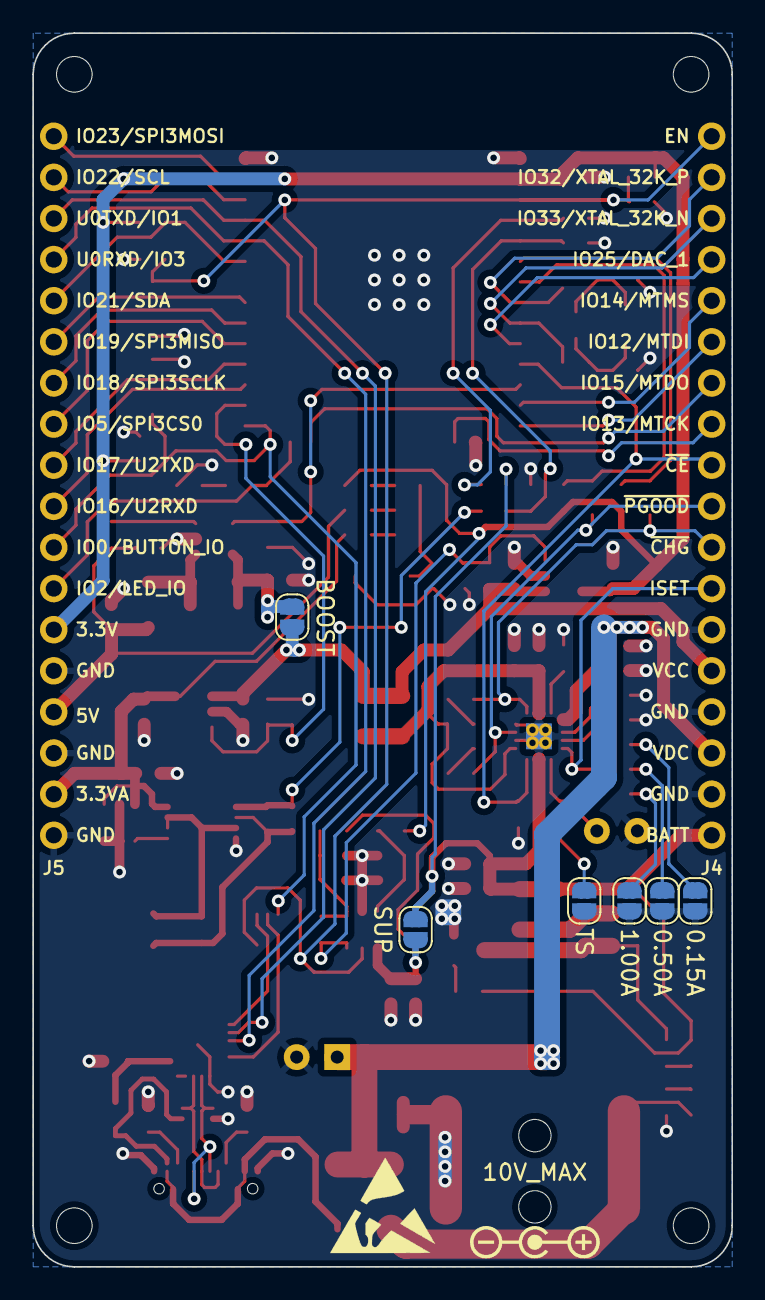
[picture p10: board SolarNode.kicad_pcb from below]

Board: 2 copper layers, 43.2 x 76.2 mm, 133 parts (8 on the bottom side), 81 nets.
